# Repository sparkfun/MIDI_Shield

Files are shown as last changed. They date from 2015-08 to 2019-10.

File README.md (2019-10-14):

SparkFun MIDI Shield
====================

SparkFun MIDI Shield (https://www.sparkfun.com/products/12898)

[*SparkFun MIDI Shield (DEV-12898)*](https://www.sparkfun.com/products/12898)

The MIDI Shield gives your Arduino access to the MIDI communication protocol, so you can control synthesizers, sequencers, and other musical devices.

Repository Contents
-------------------

* **/Firmware** - Example Arduino .ino sketch
* **/Hardware** - All Eagle design files (.brd, .sch)
* **/Production** - Production panel files (.brd)

Documentation
--------------
* **[Hookup Guide](https://learn.sparkfun.com/tutorials/midi-shield-hookup-guide?_ga=1.24780723.863167751.1453149924)** - Basic hookup guide for the MIDI Shield.
* **[SparkFun Fritzing repo](https://github.com/sparkfun/Fritzing_Parts)** - Fritzing diagrams for SparkFun products.
* **[SparkFun 3D Model repo](https://github.com/sparkfun/3D_Models)** - 3D models of SparkFun products. 
* **[SparkFun Graphical Datasheets](https://github.com/sparkfun/Graphical_Datasheets)** -Graphical Datasheets for various SparkFun products.

Product Versions
----------------
* [DEV-12898](https://www.sparkfun.com/products/12898)- Version 1.5. R3 compatible. Currently live. 
* [DEV-09595](https://www.sparkfun.com/products/retired/9595)- Version 1.3. Retired. 

Version History
---------------
* [V_1.5](https://github.com/sparkfun/MIDI_Shield/tree/V_1.5) - GitHub snapshot at V_1.5. 
* [V_1.3](https://github.com/sparkfun/MIDI_Shield/tree/v1.3) - GitHub snapshot at V_1.3

License Information
-------------------

This product is _**open source**_! 

Please review the LICENSE.md file for license information. 

If you have any questions or concerns on licensing, please contact techsupport@sparkfun.com.

Distributed as-is; no warranty is given.

\- Your friends at SparkFun.

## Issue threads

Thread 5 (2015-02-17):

90 degree trace under opto IC needs to be fixed

SFE-KADE, 2015-02-17:

Jacquot-SFE, 2015-02-17:
Can you give me an x,y coordinate?  I'm not seeing a right angle under the IC.

SFE-KADE, 2015-02-17:
Sorry, I meant "off of IC" not under. It's under the prog silk just north of the IC.

Jacquot-SFE, 2015-02-17:
Got it!

Closed 2015-02-17.

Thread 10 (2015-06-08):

brd needs measurements on measures layer

SFE-KADE, 2015-06-08:
Since there are connectors on this that can be flush mounted with a custom enclosure we should include measurements.

Jacquot-SFE, 2015-06-08:
Got 'em.

Closed 2015-06-08.

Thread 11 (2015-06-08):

Standoff holes in brd?

SFE-KADE, 2015-06-08:
Should we include them for use in an enclosure?

SFE-KADE, 2015-06-08:
I use the terms "standoff" and "mounting" here interchangeably.

Jacquot-SFE, 2015-06-08:
I skipped them on purpose.

Mechanically, this thing doesn't really provide for easy mounting in an
enclosure.  The connectors are tall, much taller than the adjacent
pushbuttons.  If it's mounted on a Uno or Redboard, the shield is
considerably shorter than the host board - the USB connector sticks out
about 3/4" past the MIDI plugs.

I suppose we could include the one hole near the SCL pin, but it's mostly
useless because it's too close to the header.

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

SFE-KADE, 2015-06-08:
Your call.

Closed 2015-06-08.

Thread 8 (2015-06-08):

version number correct?

SFE-KADE, 2015-06-08:
I think standard protocol dictates that the version number should still be v15 even though we proto'd a v15 already, only because the live version of the product is v14. The version increment should stay v15 through however many rounds of proto we do in this case. Toni, can you confirm?

Jacquot-SFE, 2015-06-08:
You're right.

(As Per an old discussion with Abe) They never made it to production, so it won't introduce inventory problems if the number doesn't roll.

Back to 1.5.

Closed 2015-06-08.

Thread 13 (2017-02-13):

using soft serial on pins 8 and 9

1mpar, 2017-02-13:
hi, I'm using this code - https://github.com/sparkfun/MIDI_Shield/blob/master/Firmware/MIDI-sniffer/MIDI-sniffer.ino
but I get no messages on the serial monitor. I think this code is for the new version of the shield, but is there a way to use soft serial on pins 8 and 9 on this version (sparkfun DEV 09595)?

Jacquot-SFE, 2017-02-17:
If you're comfortable reworking the board a little bit, this is doable.

You can cut the TX and RX lines, and add jumpers to run them to pins 8 and 9.  I'd cut the RX line near the "G" in PROG, so the 220-Ohm resistor is still tied to the optocoupler, before it reaches the RUN/PROG switch.  You can cut the TX line anywhere between the shield pin and the 220-Ohm resistor, since there's no interceding circuitry.

bboyho, 2019-02-11:
Hi,

It looks like Byron answered your question. The code is written for the latest MIDI Shield. However, as Byron stated above, you can reroute the pins on an ATmega328P-based Arduino to software serial and view the data on an Arduino Serial Monitor. Just make sure to select the correct baud rate since the output is 19200 baud.

Closed 2019-02-11.

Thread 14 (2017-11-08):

Question: how to make an arpeggio?

billyjoker, 2017-11-08:
Hi, i have this shield and i would like to write some arpeggios, but i do not know how to handle it. Thanks!!

Jacquot-SFE, 2017-11-14:
Howdy Billy,

I assume you want to build something like an arpeggiator on a keyboard, where you hold some notes, and the device will cycle through them?  If not, please add some detail about what you're trying to achieve.

I notice you found wbajzek's arpeggiator.

There's also the Mutable Instrument's [MIDIPal](https://github.com/pichenettes/midipal), which is a MIDI toolkit that includes an arpeggiator.

Finally, I put an arpeggiator in my [Werkstatt CV converter](https://learn.sparkfun.com/tutorials/midi-shield-hookup-guide/example-2-midi-to-control-voltage) project, but it outputs control voltage, not MIDI messages.  You could probably amend it to send MIDI instead.

-BGJ

billyjoker, 2017-11-15:
Hi @Jacquot-SFE !!

Yes, i'd like to trigger some arpeggiated notes when i hold on a note in my midi keyboard. You are right, i've tried the  wbajzek's arpeggiator, but the performance is not very well...

My goal is to have stored a kit of arpeggios, select one of them, and trigger it with my midi keyboard.

I've just take a look at the Mutable Instrument's MIDIPal, can i load it to my Arduino? As i saw, it is written with Python....

I'm taking a look also to your Werkstatt CV converter, is this the [code](https://github.com/sparkfun/MIDI_Shield/blob/V_1.5/Firmware/MIDI-CV/MIDI-CV.ino) ?

Thanks again!!!

Jacquot-SFE, 2017-11-16:
A couple of thoughts on this.

First, I'm not sure you're describing that a traditional arpeggiator does.  An old-school arpeggiator takes a handful of held keys, and hops between them based on some rule (up, down, up&down, random, etc).  You might check for videos of the old Roland SH101 arpeggiator in action.  It's got a pretty good one.

I take it you're looking for something that will start playing a predefined group of notes based on a single key press?  I'm not sure what it would be called, maybe an interactive phrase sequencer?

Either way, you should be able to make one using an Arduino + MIDI  shield...you just might not find one already written.

I haven't tried either wbajzek's or the MIDI pal, I just found them googling.  The MIDIPal was mentioned by a friend recently - it's based on an ATMEGA328P and standard MIDI hardware...which looks like a subset of an Uno & MIDI Shield.  The firmware is in [this subtree](https://github.com/pichenettes/midipal/tree/master/midipal), and the Python piece looks like a configuration app that runs alongside, since the MIDIpal itself only has a knob and small LCD.

Finally, that is my CV converter.  You'll also need the `notemap` files from that directory, and the fortyseven effects [MIDI library](http://github.com/FortySevenEffects/arduino_midi_library/).

bboyho, 2019-02-11:
Hi,

It looks like Byron might have answered your questions. I'll be be closing this issue. If you have not already, it might be good to check out the SparkFun or Arduino.cc Forums to see if you can get some additional insight from others in the community on arpeggios. =) :

* [Arduino.cc Forums](https://forum.arduino.cc/)
* [SparkFun Forums](https://forum.sparkfun.com/)

Closed 2019-02-11.

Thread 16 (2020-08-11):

Is this sketch only compatible with the SparkFun MIDI-shield?

m-r-m-s, 2020-08-11:
I am _not_ using the sparkfun MIDI shield but I have built a MIDI I/O circuit according to MIDI specs.

The MIDI I/O circuit works with no issues when receiving input from a sequencer and the output goes to a software synthesizer sound source. Here is a [link](https://forum.arduino.cc/index.php?topic=699623.msg4702301#msg4702301) to the I/O circuit I have built.

I have tested this circuit using the Arduino MIDI library (fortyseven effects) basic I/O and callback examples. No issues whatsoever.

The issue I am having with the MIDI-sniffer.ino sketch is that while the serial monitor seems to be reading all the MIDI data, the output seems to be getting "stuck". Notes sent from the sequencer will get stuck "on", and after I stop the sequencer, I hear a distinct echo/ feedback noise coming from the receiving sound source.

As a result, I have to reset the MIDI output (send note off / panic message) in my DAW to stop the noise from continuing and "unstick" things. Is this some kind of loopback?

Why do the basic I/O and callback examples provided in the Arduino MIDI library work but this sketch has issues? How can I work to resolve this issue? Any guidance or pointers is greatly appreciated.

Jacquot-SFE, 2020-08-14:
So the dirty little secret of NewSoftSerial - it's half-duplex.  Sending and receiving at the same time can interfere with one another.  It'll get worse as the port utilization rises - tapping one key on a MIDI controller might be OK, while heavy multi-channel sequencer (with clocks, controllers, etc) data might not.

There are a couple things to try.

To have a reliable MIDI-thru for the sniffer, you could feed the TTL signal recovered from the input straight to the output driver - that would be akin to the out/thru solder jumper (SJ3) on the shield.

Alternatively, use a chip with multiple hardware UARTs, like an Arduino Mega or Teensy.

m-r-m-s, 2020-08-14:
@Jacquot-SFE  Thank you! I figured it was something related to the sequencer's heavier input and you have certainly confirmed it. I am currently working with an UNO but will consider the Mega or Teensy for the future.

In the meantime, can you say more about "feeding the TTL signal recovered from the input straight to the output driver"?

Currently, I have a sequencer connected to my MIDI IN circuit which is connected to pin 8 (Rx) on the UNO and the MIDI OUT circuit is connected at pin 9 (Tx). Apologies in advance for the lack of knowledge, but how would I achieve what you suggested in this in the circuit?

For reference, these are the schematics of my [input](https://www.limulo.net/website/assets/images/midi-interface/MIDI_IN_bb_new.png) and [output](https://www.limulo.net/website/assets/images/midi-interface/MIDI_OUT_bb_new.png) circuit. Thank you for all the assistance so far.

Jacquot-SFE, 2020-08-17:
To make the out into a thru, unplug the purple with from Arduino pin 10.  Plug it into pin 6 of the optocoupler, where the green wire to Ard 11 is.

It's probably not the most robust solution - a typical MIDI thru uses a logic gate of some sort to buffer & drive the thru.  The shield uses a 74ahc1g125, the old MMA circuit uses series pairs of inverters (invert, then invert again).

m-r-m-s, 2020-08-17:
@Jacquot-SFE thank you so so much. Just gave the thru circuit a try and it worked great! I really appreciate your guidance here. I will look into building a more robust MIDI thru circuit with the buffer you referenced.

Closed 2020-08-20.

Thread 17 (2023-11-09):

Verify/compile of MIDI-sniffer fails

kciszewski, 2023-11-09:
When compiling on Aurdiuno IDE the error message "MIDI-sniffer:41:10: fatal error: MsTimer2.h: No such file or directory
 #include <MsTimer2.h>"

I'm using Arduino 1.8.19

Where do I find MsTimer2.h?

kciszewski, 2023-11-09:
I found it thanks!  I'm somewhat new to Arduino

edspark, 2023-11-09:
MsTImer2 is an [Arduino Library](https://www.arduino.cc/reference/en/libraries/mstimer2/) that you can find using the Library Manger. I don't have 1.8 on my computer but it's an old library that still exists even in Arduino 2.2.

edspark, 2023-11-09:
Ah you beat me to it, cheers!

Closed 2023-11-09.

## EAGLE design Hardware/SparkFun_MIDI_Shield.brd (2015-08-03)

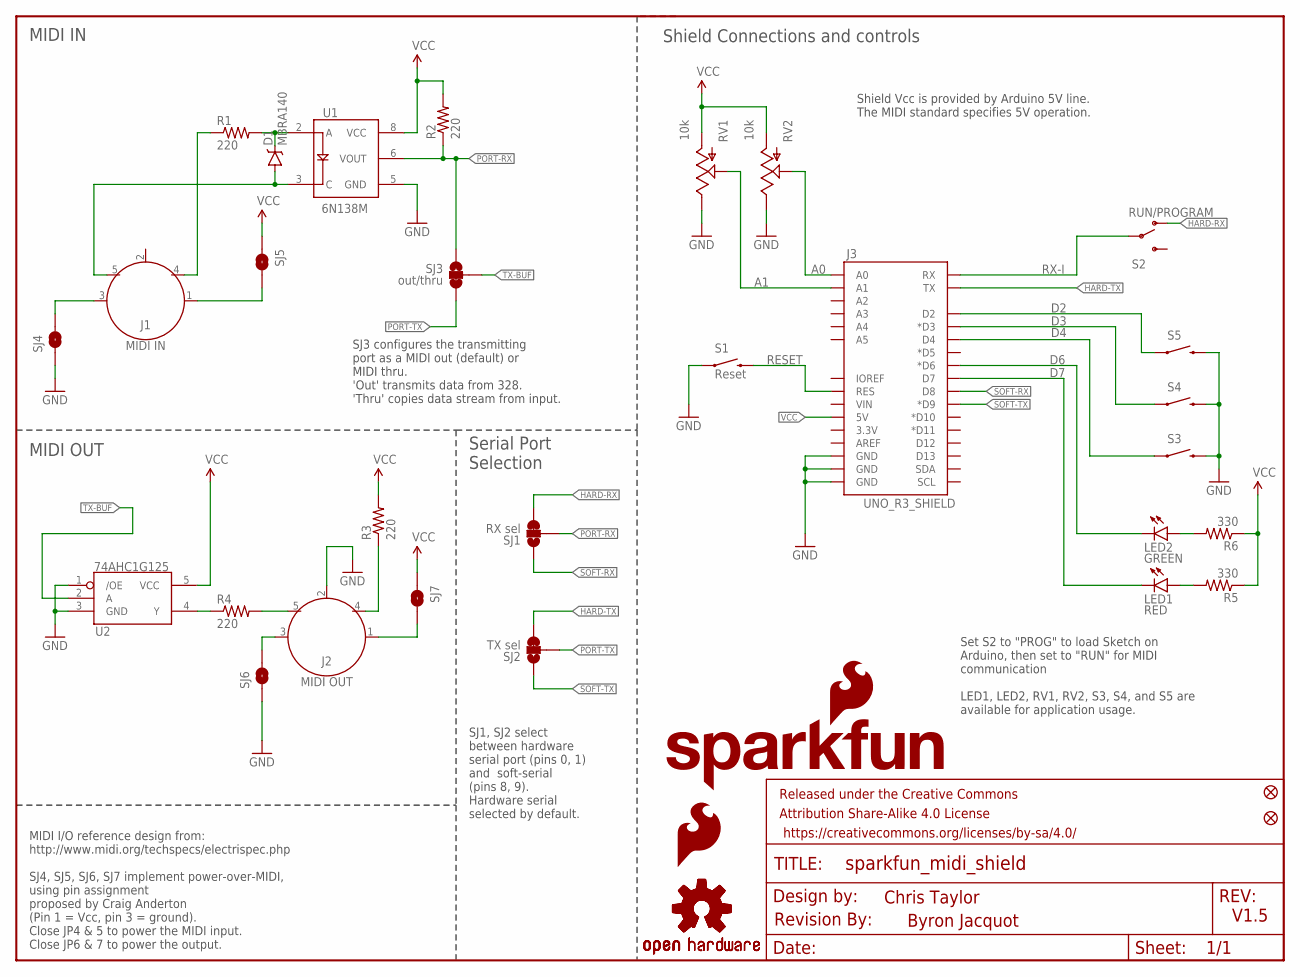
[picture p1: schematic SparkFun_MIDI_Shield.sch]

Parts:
D1: MBRA140; SMA-DIODE
FID1, FID2: FIDUCIALUFIDUCIAL; MICRO-FIDUCIAL
FRAME1: Frame; CREATIVE_COMMONS
J1: MIDI IN; 5-PIN-DIN-RA-PCB-NEW
J2: MIDI OUT; 5-PIN-DIN-RA-PCB-NEW
J3: UNO_R3_SHIELD
LED1: RED; LED-0603
LED2: GREEN; LED-0603
LOGO1: SFE_LOGO_NAME_FLAME.2_INCH; SFE_LOGO_NAME_FLAME_.2
LOGO2: OSHW-LOGOS; OSHW-LOGO-S
LOGO3: OSHW-LOGOM; OSHW-LOGO-M
LOGO5: SFE_LOGO_FLAME.1_INCH; SFE_LOGO_FLAME_.1
R1, R2, R3, R4: 220; 0603-RES
R5, R6: 330; 0603-RES
RV1, RV2: 10k; ALPS_POT
S1: Reset; TACTILE-SWITCH-SMD
S2: RUN/PROGRAM; AYZ0202
S3, S4, S5: SWITCH-MOMENTARY-212MM; TACTILE-PTH-12MM
SJ1: RX sel; PAD-JUMPER-3-2OF3_NC_BY_TRACE_YES_SILK_FULL_BOX
SJ2: TX sel; PAD-JUMPER-3-2OF3_NC_BY_TRACE_YES_SILK_FULL_BOX
SJ3: out/thru; PAD-JUMPER-3-2OF3_NC_BY_TRACE_YES_SILK_FULL_BOX
SJ4, SJ5, SJ6, SJ7: JUMPER-PAD-2-NOYES_SILK; PAD-JUMPER-2-NO_YES_SILK
U1: 6N138M; 8-SMD
U2: 74AHC1G125; SOT23-5
U$1: REVISION

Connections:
56: D1.C, R1.2, U1.2 (A)
1235: J2.4, R3.1
A0: J3.A0, RV2.P$2 (S)
A1: J3.A1, RV1.P$2 (S)
D2: J3.D2, S5.1
D3: J3.D3 (*D3), S4.1
D4: J3.D4, S3.1
D6: J3.D6 (*D6), LED2.C
D7: J3.D7, LED1.C
GND: J2.2, J3.GND@0 (GND), J3.GND@1 (GND), J3.GND@2 (GND), RV1.P$1 (E), RV2.P$1 (E), S1.1, S3.3 (2), S4.3 (2), S5.3 (2), SJ4.1, SJ6.1, U1.5 (GND), U2.1 (/OE), U2.3 (GND)
HARD-RX: S2.1 (O), SJ1.3
HARD-TX: J3.TX, SJ2.3
unnamed: J2.5, R4.2
unnamed: J1.4, R1.1
unnamed: R4.1, U2.4 (Y)
unnamed: J2.3, SJ6.2
unnamed: J2.1, SJ7.2
unnamed: J1.3, SJ4.2
unnamed: J1.1, SJ5.2
unnamed: LED1.A, R5.2
unnamed: LED2.A, R6.2
PIN5: D1.A, J1.5, U1.3 (C)
PORT-RX: R2.1, SJ1.2, SJ3.1, U1.6 (VOUT)
PORT-TX: SJ2.2, SJ3.3
RESET: J3.RES, S1.3 (2)
RX-I: J3.RX, S2.2
SOFT-RX: J3.D8, SJ1.1
SOFT-TX: J3.D9 (*D9), SJ2.1
TX-BUF: SJ3.2, U2.2 (A)
VCC: J3.5V, R2.2, R3.2, R5.1, R6.1, RV1.P$3 (A), RV2.P$3 (A), SJ5.1, SJ7.1, U1.8 (VCC), U2.5 (VCC)

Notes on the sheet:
MIDI IN
MIDI OUT
Byron Jacquot
V1.5
Shield Connections and controls
MIDI I/O reference design from: http://www.midi.org/techspecs/electrispec.php SJ4, SJ5, SJ6, SJ7 implement power-over-MIDI, using pin assignment proposed by Craig Anderton (Pin 1 = Vcc, pin 3 = ground). Close JP4 & 5 to power the MIDI input. Close JP6 & 7 to power the output.
Set S2 to "PROG" to load Sketch on Arduino, then set to "RUN" for MIDI communication LED1, LED2, RV1, RV2, S3, S4, and S5 are available for application usage.
Serial Port Selection
SJ1, SJ2 select between hardware serial port (pins 0, 1) and soft-serial (pins 8, 9). Hardware serial selected by default.
Shield Vcc is provided by Arduino 5V line. The MIDI standard specifies 5V operation.
SJ3 configures the transmitting port as a MIDI out (default) or MIDI thru. 'Out' transmits data from 328. 'Thru' copies data stream from input.
Chris Taylor

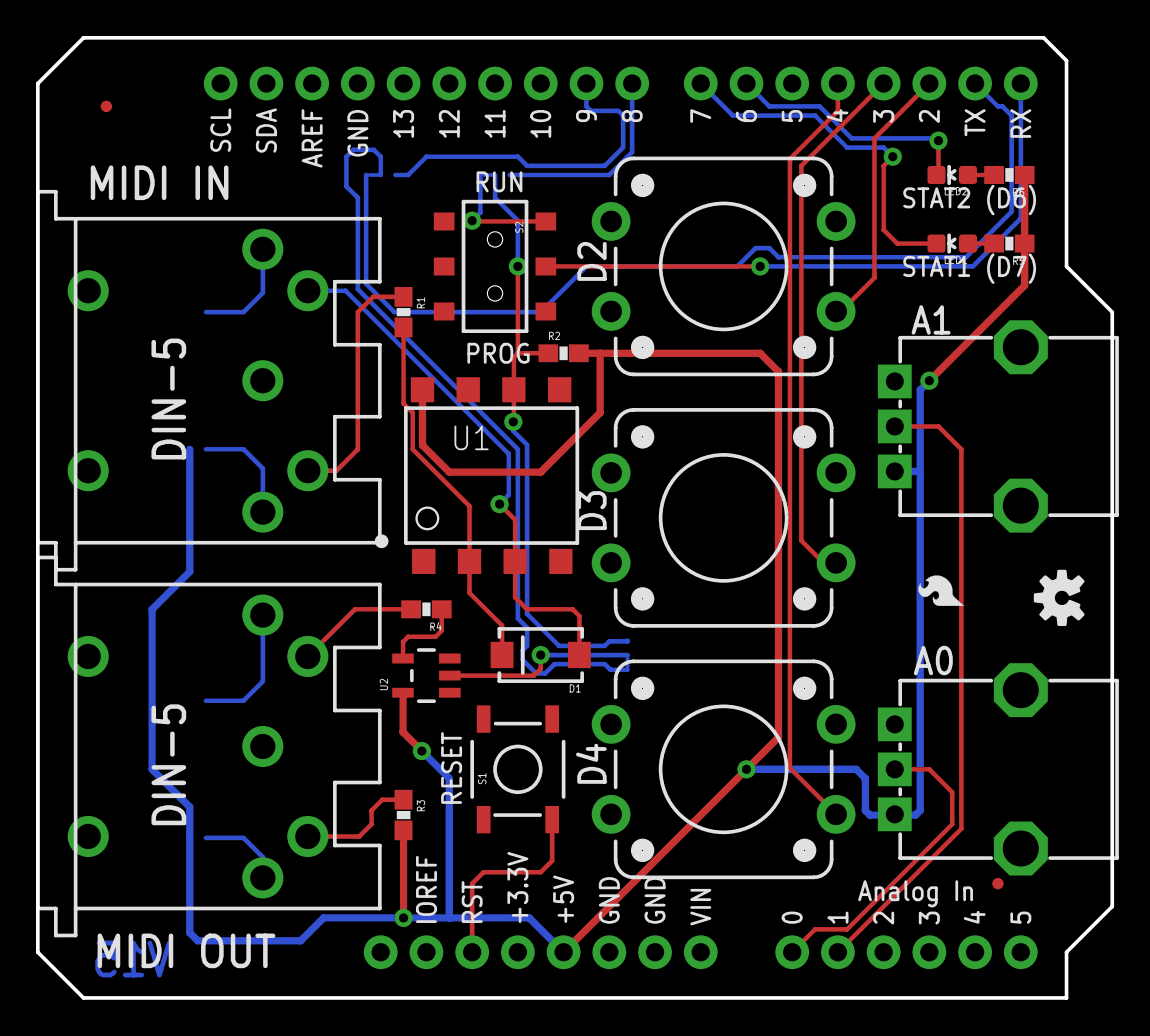
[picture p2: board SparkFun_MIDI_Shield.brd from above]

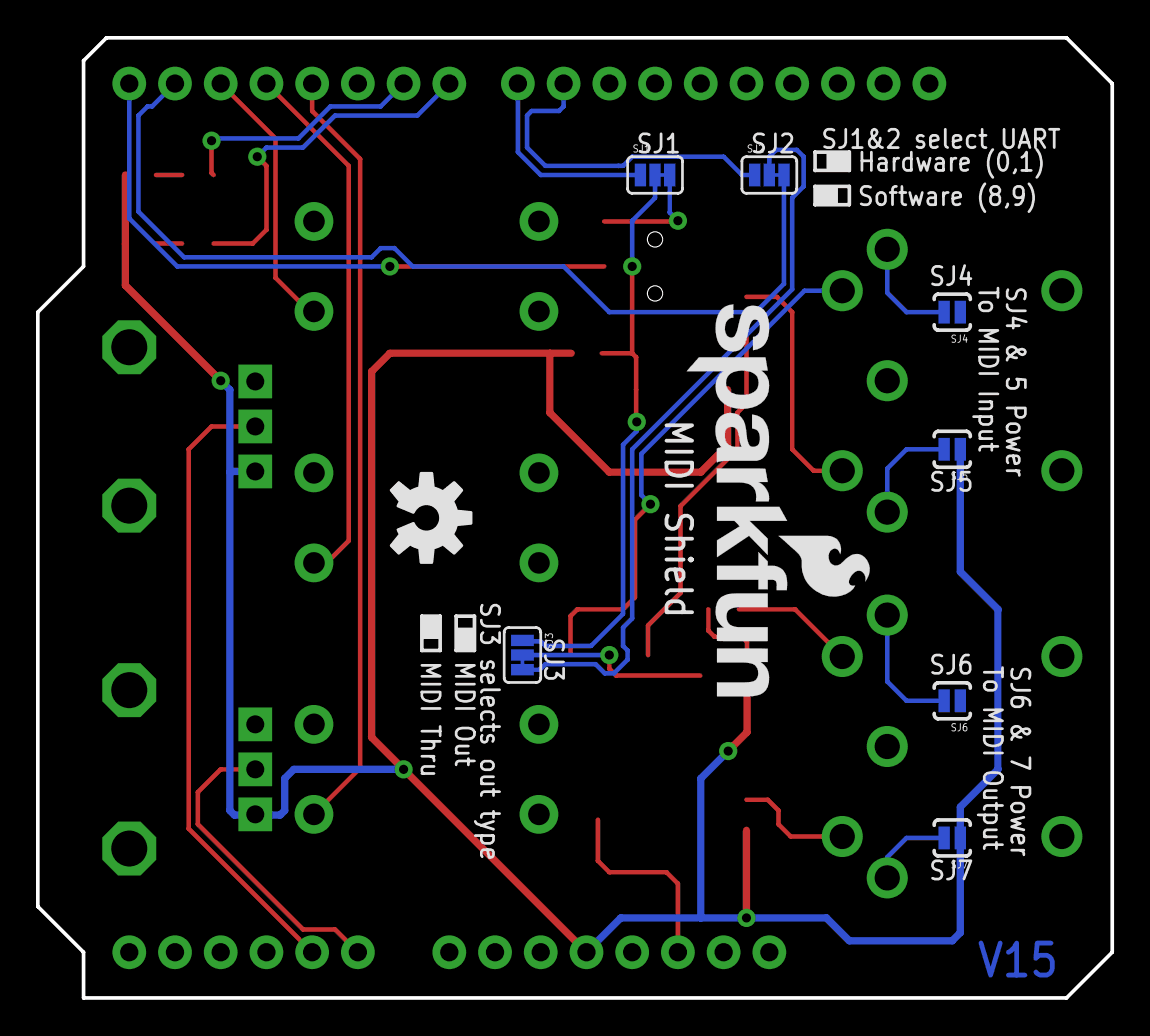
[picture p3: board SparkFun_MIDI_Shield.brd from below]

Board: 3 copper layers, 59.7 x 53.3 mm, 36 parts (9 on the bottom side), 30 nets.

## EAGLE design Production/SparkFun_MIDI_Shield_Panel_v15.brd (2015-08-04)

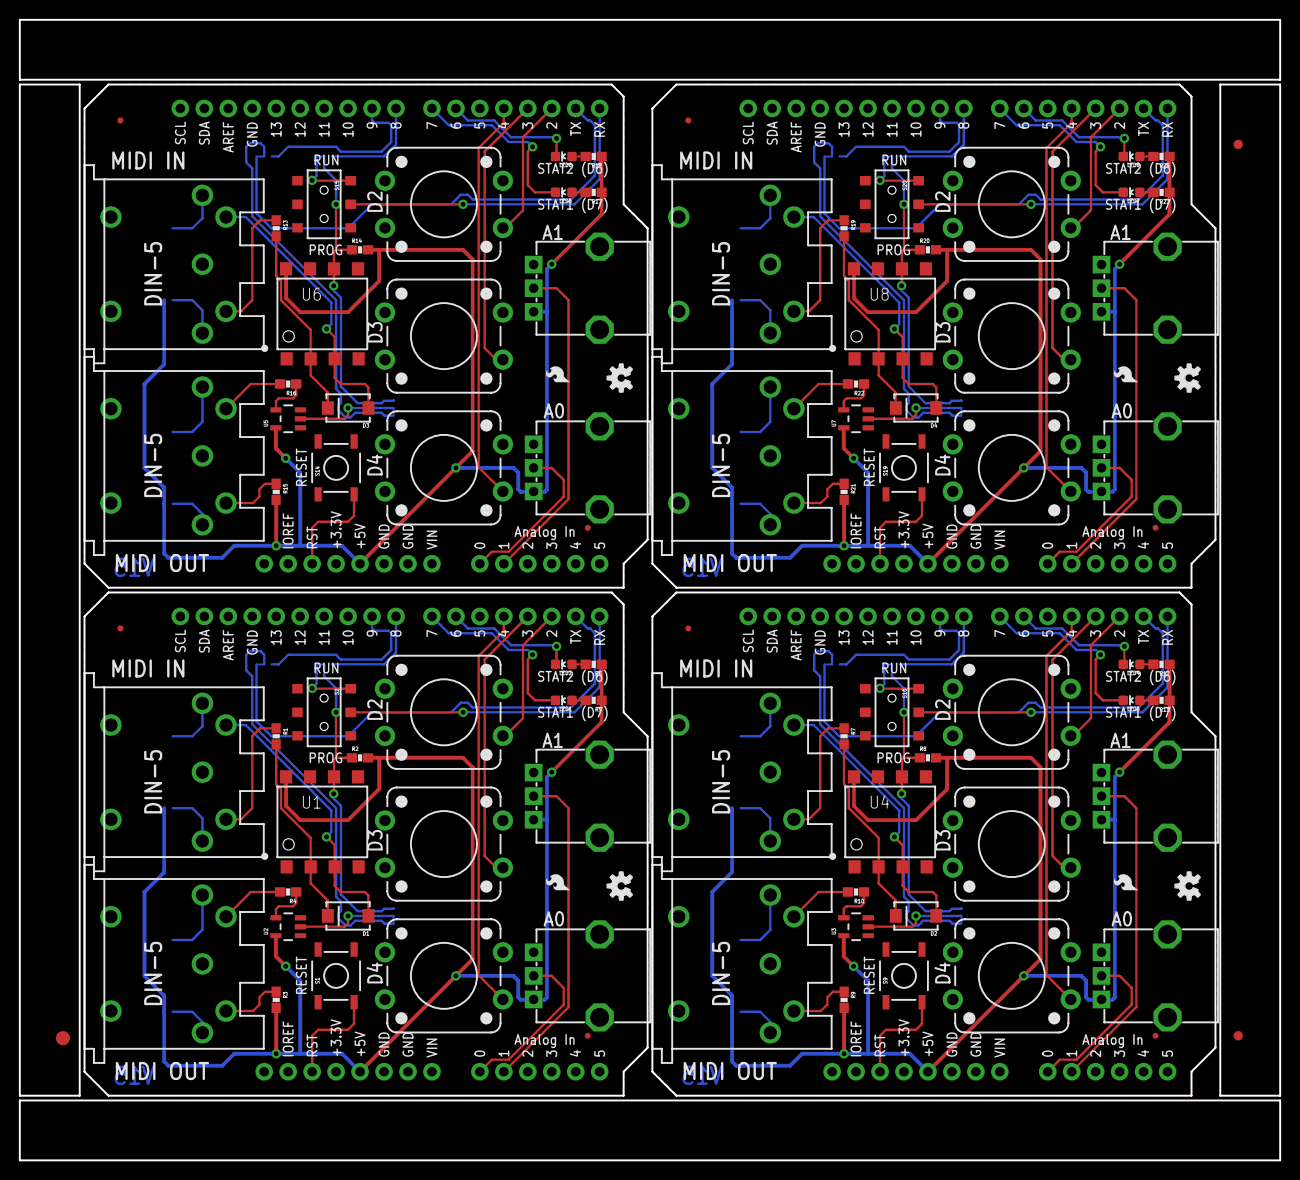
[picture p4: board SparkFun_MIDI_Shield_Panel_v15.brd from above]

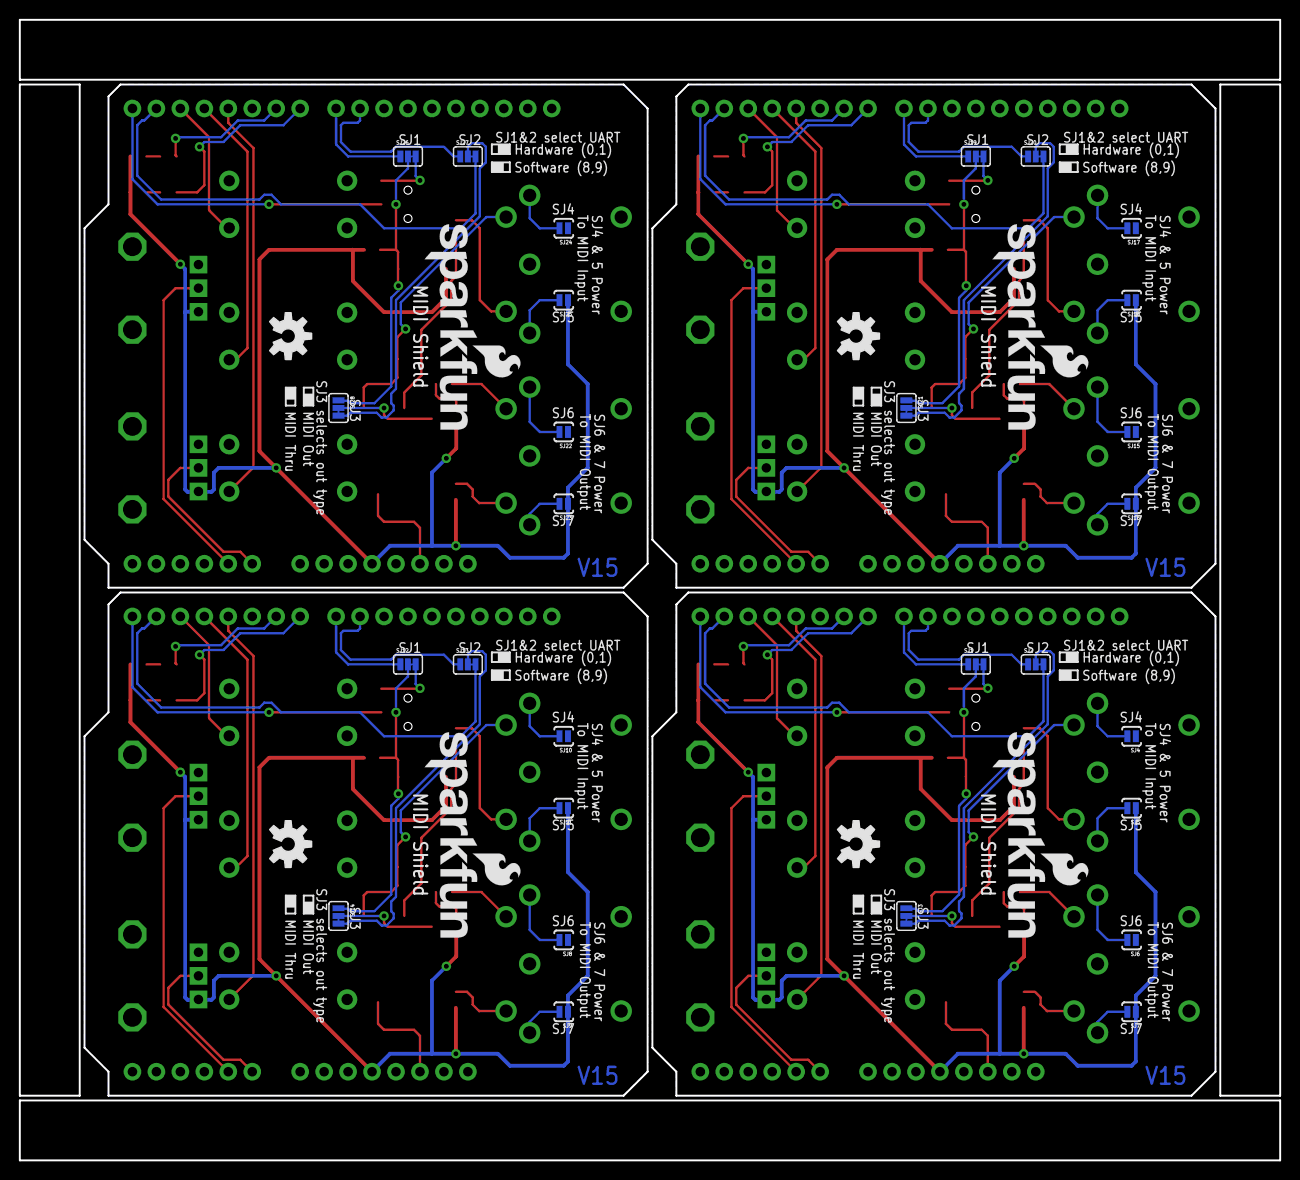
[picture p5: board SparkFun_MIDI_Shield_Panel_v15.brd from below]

Board: 3 copper layers, 133.6 x 120.9 mm, 139 parts (36 on the bottom side), 120 nets.

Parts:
D1, D2, D3, D4: MBRA140; SMA-DIODE
E$1: FIDUCIAL-1.5X3
E$4, E$5: FIDUCIAL-1X2
FID1, FID2, FID3, FID4, FID5, FID6, FID7, FID8: FIDUCIALUFIDUCIAL; MICRO-FIDUCIAL
J1, J4, J7, J10: MIDI IN; 5-PIN-DIN-RA-PCB-NEW
J2, J5, J8, J11: MIDI OUT; 5-PIN-DIN-RA-PCB-NEW
J3, J6, J9, J12: UNO_R3_SHIELD
LED1, LED3, LED5, LED7: RED; LED-0603
LED2, LED4, LED6, LED8: GREEN; LED-0603
LOGO1, LOGO4, LOGO9, LOGO13: SFE_LOGO_NAME_FLAME.2_INCH; SFE_LOGO_NAME_FLAME_.2
LOGO2, LOGO6, LOGO10, LOGO14: OSHW-LOGOS; OSHW-LOGO-S
LOGO3, LOGO7, LOGO11, LOGO15: OSHW-LOGOM; OSHW-LOGO-M
LOGO5, LOGO8, LOGO12, LOGO16: SFE_LOGO_FLAME.1_INCH; SFE_LOGO_FLAME_.1
R1, R2, R3, R4, R7, R8, R9, R10, R13, R14, R15, R16, R19, R20, R21, R22: 220; 0603-RES
R5, R6, R11, R12, R17, R18, R23, R24: 330; 0603-RES
RV1, RV2, RV3, RV4, RV5, RV6, RV7, RV8: 10k; ALPS_POT
S1, S9, S14, S19: Reset; TACTILE-SWITCH-SMD
S2, S10, S15, S20: RUN/PROGRAM; AYZ0202
S3, S4, S5, S6, S7, S8, S11, S12, S13, S16, S17, S18: SWITCH-MOMENTARY-212MM; TACTILE-PTH-12MM
SJ1, SJ12, SJ19, SJ26: RX sel; PAD-JUMPER-3-2OF3_NC_BY_TRACE_YES_SILK_FULL_BOX
SJ2, SJ13, SJ20, SJ27: TX sel; PAD-JUMPER-3-2OF3_NC_BY_TRACE_YES_SILK_FULL_BOX
SJ3, SJ14, SJ21, SJ28: out/thru; PAD-JUMPER-3-2OF3_NC_BY_TRACE_YES_SILK_FULL_BOX
SJ4, SJ5, SJ6, SJ7, SJ8, SJ9, SJ10, SJ11, SJ15, SJ16, SJ17, SJ18, SJ22, SJ23, SJ24, SJ25: JUMPER-PAD-2-NOYES_SILK; PAD-JUMPER-2-NO_YES_SILK
U1, U4, U6, U8: 6N138M; 8-SMD
U2, U3, U5, U7: 74AHC1G125; SOT23-5

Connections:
1: D2.C, R7.2, U4.2
2: J5.4, R9.1
3: D3.C, R13.2, U6.2
4: J8.4, R15.1
5: D4.C, R19.2, U8.2
6: J11.4, R21.1
56: D1.C, R1.2, U1.2
1235: J2.4, R3.1
A0: J3.A0, RV2.P$2
A1: J3.A1, RV1.P$2
A2: J6.A1, RV3.P$2
A3: J6.A0, RV4.P$2
A4: J9.A1, RV5.P$2
A5: J9.A0, RV6.P$2
A6: J12.A1, RV7.P$2
A7: J12.A0, RV8.P$2
D1: J6.D2, S8.1
D2: J3.D2, S5.1
D3: J3.D3, S4.1
D4: J3.D4, S3.1
D5: J6.D3, S7.1
D6: J3.D6, LED2.C
D7: J3.D7, LED1.C
D8: J6.D4, S6.1
D9: J6.D7, LED3.C
D10: J6.D6, LED4.C
D11: J9.D2, S13.1
D12: J9.D3, S12.1
D13: J9.D4, S11.1
D14: J9.D7, LED5.C
D15: J9.D6, LED6.C
D16: J12.D2, S18.1
D17: J12.D3, S17.1
D18: J12.D4, S16.1
D19: J12.D7, LED7.C
D20: J12.D6, LED8.C
GND: J2.2, J3.GND@0, J3.GND@1, J3.GND@2, RV1.P$1, RV2.P$1, S1.1, S3.3, S4.3, S5.3, SJ4.1, SJ6.1, U1.5, U2.1, U2.3
GND1: J5.2, J6.GND@0, J6.GND@1, J6.GND@2, RV3.P$1, RV4.P$1, S6.3, S7.3, S8.3, S9.1, SJ8.1, SJ10.1, U3.1, U3.3, U4.5
GND2: J8.2, J9.GND@0, J9.GND@1, J9.GND@2, RV5.P$1, RV6.P$1, S11.3, S12.3, S13.3, S14.1, SJ15.1, SJ17.1, U5.1, U5.3, U6.5
GND3: J11.2, J12.GND@0, J12.GND@1, J12.GND@2, RV7.P$1, RV8.P$1, S16.3, S17.3, S18.3, S19.1, SJ22.1, SJ24.1, U7.1, U7.3, U8.5
HARD-RX: S2.1, SJ1.3
HARD-RX1: S10.1, SJ12.3
HARD-RX2: S15.1, SJ19.3
HARD-RX3: S20.1, SJ26.3
HARD-TX: J3.TX, SJ2.3
HARD-TX1: J6.TX, SJ13.3
HARD-TX2: J9.TX, SJ20.3
HARD-TX3: J12.TX, SJ27.3
unnamed: J2.5, R4.2
unnamed: J1.4, R1.1
unnamed: R4.1, U2.4
unnamed: J2.3, SJ6.2
unnamed: J2.1, SJ7.2
unnamed: J1.3, SJ4.2
unnamed: J1.1, SJ5.2
unnamed: LED3.A, R11.2
unnamed: LED1.A, R5.2
unnamed: LED2.A, R6.2
unnamed: LED4.A, R12.2
unnamed: J4.4, R7.1
unnamed: J5.5, R10.2
unnamed: R10.1, U3.4
unnamed: J5.3, SJ8.2
unnamed: J5.1, SJ9.2
unnamed: J4.3, SJ10.2
unnamed: J4.1, SJ11.2
unnamed: LED5.A, R17.2
unnamed: LED6.A, R18.2
unnamed: J7.4, R13.1
unnamed: J8.5, R16.2
unnamed: R16.1, U5.4
unnamed: J8.3, SJ15.2
unnamed: J8.1, SJ16.2
unnamed: J7.3, SJ17.2
unnamed: J7.1, SJ18.2
unnamed: LED7.A, R23.2
unnamed: LED8.A, R24.2
unnamed: J10.4, R19.1
unnamed: J11.5, R22.2
unnamed: R22.1, U7.4
unnamed: J11.3, SJ22.2
unnamed: J11.1, SJ23.2
unnamed: J10.3, SJ24.2
unnamed: J10.1, SJ25.2
PIN1: D2.A, J4.5, U4.3
PIN2: D3.A, J7.5, U6.3
PIN3: D4.A, J10.5, U8.3
PIN5: D1.A, J1.5, U1.3
PORT-RX: R2.1, SJ1.2, SJ3.1, U1.6
PORT-RX1: R8.1, SJ12.2, SJ14.1, U4.6
PORT-RX2: R14.1, SJ19.2, SJ21.1, U6.6
PORT-RX3: R20.1, SJ26.2, SJ28.1, U8.6
PORT-TX: SJ2.2, SJ3.3
PORT-TX1: SJ13.2, SJ14.3
PORT-TX2: SJ20.2, SJ21.3
PORT-TX3: SJ27.2, SJ28.3
RESET: J3.RES, S1.3
RESET1: J6.RES, S9.3
RESET2: J9.RES, S14.3
RESET3: J12.RES, S19.3
RX-I: J3.RX, S2.2
RX-I1: J6.RX, S10.2
RX-I2: J9.RX, S15.2
RX-I3: J12.RX, S20.2
SOFT-RX: J3.D8, SJ1.1
SOFT-RX1: J6.D8, SJ12.1
SOFT-RX2: J9.D8, SJ19.1
SOFT-RX3: J12.D8, SJ26.1
SOFT-TX: J3.D9, SJ2.1
SOFT-TX1: J6.D9, SJ13.1
SOFT-TX2: J9.D9, SJ20.1
SOFT-TX3: J12.D9, SJ27.1
TX-BUF: SJ3.2, U2.2
TX-BUF1: SJ14.2, U3.2
TX-BUF2: SJ21.2, U5.2
TX-BUF3: SJ28.2, U7.2
VCC: J3.5V, R2.2, R3.2, R5.1, R6.1, RV1.P$3, RV2.P$3, SJ5.1, SJ7.1, U1.8, U2.5
VCC1: J6.5V, R8.2, R9.2, R11.1, R12.1, RV3.P$3, RV4.P$3, SJ9.1, SJ11.1, U3.5, U4.8
VCC2: J9.5V, R14.2, R15.2, R17.1, R18.1, RV5.P$3, RV6.P$3, SJ16.1, SJ18.1, U5.5, U6.8
VCC3: J12.5V, R20.2, R21.2, R23.1, R24.1, RV7.P$3, RV8.P$3, SJ23.1, SJ25.1, U7.5, U8.8

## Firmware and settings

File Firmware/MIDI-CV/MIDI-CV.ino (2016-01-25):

/******************************************************************************
MIDI-CV.ino
MIDI to Control Voltage converter for synthesizers.
Byron Jacquot, SparkFun Electronics
October 2, 2015
https://github.com/sparkfun/MIDI_Shield/tree/V_1.5/Firmware/MIDI-CV

This functions as a MIDI-to-control voltage interface for analog synthesizers.
It was developed for the Moog Werkstatt WS-01, but should work with any volt-per-octave
synthesizer.

Resources:
  This code is dependent on the FortySevenEffects MIDI library for Arduino.
  https://github.com/FortySevenEffects/arduino_midi_library
  This was done using version 4.2, hash fb693e724508cb8a473fa0bf1915101134206c34
  This library is now under the MIT license, as well.
  You'll need to install that library into the Arduino IDE before compiling.

  It is also dependent on the notemap class, stored in the same repository (notemap.cpp/h).

Development environment specifics:
  It was developed for the Arduino Uno compatible SparkFun RedBoard, with a  SparkFun
  MIDI Shield and a pair of Microchip MCP4725 DACs to generate the control voltages.
    
  Written, compiled and loaded with Arduino 1.6.5

This code is released under the [MIT License](http://opensource.org/licenses/MIT).

Please review the LICENSE.md file included with this example. If you have any questions 
or concerns with licensing, please contact techsupport@sparkfun.com.

Distributed as-is; no warranty is given.
******************************************************************************/

#include <SoftwareSerial.h>
#include <MsTimer2.h>
#include <MIDI.h>
#include <Wire.h>

#include "notemap.h"

// VERBOSE mode switches MIDI to use soft serial on pins 8 & 9,
// and enables a bunch of debug print messages.
#define VERBOSE 0

// Instantiate the MIDI interface using the macro
// - HardwareSerial is the type of serial port to be used underneath
// the MIDI routines.
// - Serial1 is the name of that portto be used.  On a pro-micro, "Serial"
// is the USB serial port, and "Serial1" is the hardware UART.
// - "MIDI" parameter is the resulting object name.
#if VERBOSE
SoftwareSerial SoftSerial(8, 9);
MIDI_CREATE_INSTANCE(SoftwareSerial, SoftSerial, MIDI);
#else
MIDI_CREATE_INSTANCE(HardwareSerial, Serial, MIDI);
#endif

// Functional assignments to Arduino pin numbers.
// Digital outputs
static const int GATEPIN = 10;
static const int REDLEDPIN = 7;
static const int GREENLEDPIN = 6;

// Analog input
static const int PIN_TEMPO_POT = 1;

// Digital inputs
static const int UPBTNPIN = 2;
static const int DNBTNPIN  = 3;
static const int SHORTBTNPIN= 4;
static const int BTN_DEBOUNCE = 50;

// global variables
//
// notetracker knows which note ons & offs we have seen.
// We refer to it when it's time to generate CV and gate signals,
static notetracker themap;

// Variables for arpeggiator clock.
static uint32_t tempo_delay = 10;
static bool     send_tick = false;

// The last bend records the most recently seen bend message.
// We need to keep track so we can update note CV when we get new notes,
// or new bend messages - we need the other half in order to put them together.
// bend is signed, 14-bit
static int16_t last_bend = 0;

// constants to describe the MIDI input.
// NUM_KEYS is the number of keys we're interpreting
// BASE_KEY is the offset of the lowest key number
static const int8_t NUM_KEYS = 49;
static const int8_t BASE_KEY = 36;

// The tuning constant - representing the DAC conts per semitone
//
// Arrived at using: (((2^<DAC resolution>)/5)/12) * 100
//
// 2^12 = 4096 total DAC counts.
// 4096/5 = 819.2 DAC counts per volt on a 5V supply
// 819.2/12 = dac counts per semitone = 68.26
// times 100 for some extra calculation precision = 6826
static const uint32_t DAC_CAL = 6826;

/* 
 *  void updateCV(uint8_t key)
 *  
 *Converts key number to DAC count value,
 *and sends the value tio the DAC
 */ 
void updateCV(uint8_t key)
{  
#if 0
  Serial.print("KEY: ");
  Serial.print(key);
#endif
  uint32_t val = 400ul + ((key * DAC_CAL)/100ul);

#if 0
  val = last_key * 6826ul;
  Serial.print(" VALa: ");
  Serial.print(val, HEX);
  
  val /= 100;
  Serial.print(" VALb: ");
  Serial.print(val, HEX);

  val += 400 ;
  Serial.print(" VALc: ");
  Serial.print(val, HEX);
#endif
  val += last_bend;

//  Serial.print(" VAL2: ");
//  Serial.println(val, HEX);


  Wire.beginTransmission(0x60);
  Wire.write(byte((val & 0x0f00) >> 8));
  Wire.write(byte(val & 0xff));
  Wire.endTransmission();

}

/*
 * void updateOutputs()
 * 
 *  Update otputs sets the outputs to the current conditions.
 *  Called from note on, note off, arp tick.
 */
void updateOutputs()
{
  uint8_t key;

  key = themap.whichKey();

#if VERBOSE
  Serial.print("key: ");
  Serial.println(key, HEX);
#endif

  // key is in terms of MIDI note number.
  // Constraining the key number to 4 octave range
  // Soc we can do 4 Volts +/- ~0.5V bend range.
  if (key < BASE_KEY)
  {
    key = 0;
  }
  else if ( key > BASE_KEY + NUM_KEYS)
  {
    key = NUM_KEYS;
  }
  else
  {
    key -= BASE_KEY;
  }

  updateCV(key);

  digitalWrite(GATEPIN, themap.getGate());
}

/////////////////////////////////////////////////////////////////////////
// Callbacks for the MIDI parser
/////////////////////////////////////////////////////////////////////////

/* void handleNoteOn(byte channel, byte pitch, byte velocity)
 *  
 *  Called by MIDI parser when note on messages arrive.
 */
void handleNoteOn(byte channel, byte pitch, byte velocity)
{
  // Do whatever you want when a note is pressed.
  // Try to keep your callbacks short (no delays ect)
  // otherwise it would slow down the loop() and have a bad impact
  // on real-time performance.

  Serial.print("on: ");
  Serial.println(pitch , HEX);

  themap.noteOn(pitch);

  updateOutputs();

}

/* void handleNoteOff(byte channel, byte pitch, byte velocity)
 *  
 *  Called by MIDI parser when note off messages arrive.
 */
void handleNoteOff(byte channel, byte pitch, byte velocity)
{
  // Do something when the note is released.
  // Note that NoteOn messages with 0 velocity are interpreted as NoteOffs.
  Serial.print("off: ");
  Serial.println(pitch , HEX);

  themap.noteOff(pitch);

  updateOutputs();
}

/*void handlePitchBend(byte channel, int bend)
 * 
 * Called by parser when bend messages arrive.
 */
void handlePitchBend(byte channel, int bend)
{
#if VERBOSE
  Serial.print("bend: ");
  Serial.println(bend , HEX);
#endif
  // Bend data from the parser is 14 bits, signed, centered
  // on 0.
  // unsigned conversion & dual-7-bit thwacking 
  // already handled by midi parser

  last_bend = bend >> 5;

#if VERBOSE
  Serial.print("newbend: ");
  Serial.println(last_bend, HEX);
#endif

  updateOutputs();
}

/* void handleCC(byte channel, byte number, byte value)
 *  
 *  Called by parser when continuous controller message arrive
 */
void handleCC(byte channel, byte number, byte value)
{
#if VERBOSE
  Serial.print("cc: ");
  Serial.print(number);
  Serial.print(" chan: ");
  Serial.print(channel, HEX);
  Serial.print("val: ");
  Serial.println(value, HEX);
#endif

  switch (number)
  {
    case 1:
    { // Mod wheel

      Wire.beginTransmission(0x61);
      // Turn 7 bits into 12
      Wire.write(byte((value & 0x70) >> 3));
      Wire.write(byte((value & 0x0f) << 4));
      Wire.endTransmission();
    };
    break;
    case 64:
    { // sustain pedal
      themap.setSustain( (value != 0) );            
    }

    // Other CC's would line up here...

    default:
      break;
  }

}

/////////////////////////////////////////////////////////////////////////
// millisecond timer related
//
// See documentation for MStimer2 (http://playground.arduino.cc/Main/MsTimer2).
////////////////////////////////////////////////////////////////////////

void timer_callback()
{
  // Tell the mainline loop that time has elapsed
  send_tick = true;
}

/* void tick_func()
 *  
 * Called by mainline loop when send_tick is true.
 * Keeps track of rising/falling edges, and notifies notetracker
 * of clock status.
 */
void tick_func()
{
  static uint8_t counter = 0;  

  counter++;

  if(counter & 0x01)
  {
    digitalWrite(REDLEDPIN, HIGH);

    themap.tickArp(false);
    updateOutputs();
  }
  else
  {
    digitalWrite(REDLEDPIN, LOW);

    themap.tickArp(true);
    updateOutputs();
  }
}

/////////////////////////////////////////////////////////////////////////
// Panel interface control routines
/////////////////////////////////////////////////////////////////////////

/*void check_pots()
 * 
 * Read the analog input (tempo control)
 */
void check_pots()
{
  uint32_t pot_val;
  uint32_t calc;
  
  pot_val = analogRead(PIN_TEMPO_POT);
  
  // Result is 10 bits
  //calc = (((0x3ff - pot_val) * 75)/1023) + 8;
  calc = (((0x3ff - pot_val) * 1800)/1023) + 25;
  
  tempo_delay = calc  ;

}

/* void up_btn_func()
 *  
 *  Called when button reader detects arpeggio up button has been pressed.
 *  
 *  If not in up mode, turn on up mode.
 *  If in up mode, stops arpeggiator.
 */
void up_btn_func()
{
#if VERBOSE  
  Serial.println("Up!");
#endif

  if(themap.getMode() == notetracker::ARP_UP)
  {
    digitalWrite(GREENLEDPIN, HIGH);
    themap.setMode(notetracker::NORMAL);
  }
  else
  {
    digitalWrite(GREENLEDPIN, LOW);
    themap.setMode(notetracker::ARP_UP);
  }
}

/* void dn_btn_func()
 *  
 *  Called when button reader detects arpeggio up button has been pressed.
 *  
 *  If not in dn mode, turn on up mode.
 *  If in dn mode, stops arpeggiator.
 */
void dn_btn_func()
{
#if VERBOSE  
  Serial.println("Dn!");
#endif
  
  if(themap.getMode() == notetracker::ARP_DN)
  {
    digitalWrite(GREENLEDPIN, HIGH);
    themap.setMode(notetracker::NORMAL);
  }
  else
  {
    digitalWrite(GREENLEDPIN, LOW);
    themap.setMode(notetracker::ARP_DN);
  }
}

/* void short_btn_func()
 *  
 *  Toggles staccato articulations
 *  Works independently of arpeggiator enablement.
 */
void short_btn_func()
{
#if VERBOSE  
  Serial.print("Short!");
#endif

  if(themap.getShort())
  {
    themap.setShort(false);
  }
  else
  {
    themap.setShort(true);
  }
}

/* Button behavior function array for ease of referencing using index
 *  
 */
void(*func_array[3])(void) = 
{
  up_btn_func,
  dn_btn_func,
  short_btn_func
};

/* void check_buttons()
 *  
 *  Implements debounced button polling for the 3 buttons on then MIDI shield.
 *  
 *  Buttons are active low, pulled up.
 *  On a poll cycle, reads each button.
 *  If button is pressed (LOW), it counts up.
 *  If button is held for enough cycles, it calls the indirect routine for the button.
 *  When button is released, debounce counter clears.
 */
void check_buttons()
{
  static uint8_t deb_array[3];
  uint8_t val;

  for(uint8_t i = 0; i < 3; i++)
  {
    // active low, pulled high
    val = digitalRead(i + UPBTNPIN);

    if(val == LOW)
    {
      if(deb_array[i] < BTN_DEBOUNCE+1)
      {
        deb_array[i]++;

        if(deb_array[i] == BTN_DEBOUNCE)
        {
          (*func_array[i])();
        }
      }
    }
    else
    {
      deb_array[i] = 0;
    }
  }
}

/////////////////////////////////////////////////////////////////////////
// Arduino boilerplate - setup() & loop()
/////////////////////////////////////////////////////////////////////////

void setup()
{
  // Output pins
  pinMode(GATEPIN, OUTPUT);   
  pinMode(REDLEDPIN, OUTPUT);
  pinMode(GREENLEDPIN, OUTPUT);

  digitalWrite(REDLEDPIN, HIGH);
  digitalWrite(GREENLEDPIN, HIGH);

  // Button pins
  pinMode(UPBTNPIN, INPUT_PULLUP);
  pinMode(DNBTNPIN, INPUT_PULLUP);
  pinMode(SHORTBTNPIN, INPUT_PULLUP);

  Serial.begin(115200); //This pipes to the serial monitor

  Wire.begin();

  // Initiate MIDI communications, listen to all channels
  // .begin sets the thru mode to on, so we'll have to turn it off if we don't want echo
  MIDI.begin(MIDI_CHANNEL_OMNI);

  MIDI.turnThruOff();

  // so it is called upon reception of a NoteOn.
  MIDI.setHandleNoteOn(handleNoteOn);  // Put only the name of the function
  // Do the same for NoteOffs
  MIDI.setHandleNoteOff(handleNoteOff);
  MIDI.setHandleControlChange(handleCC);
  MIDI.setHandlePitchBend(handlePitchBend);

  MsTimer2::set(tempo_delay, timer_callback);
  MsTimer2::start();

  Serial.println("setup complete");
}

void loop()
{
  // Pump the MIDI parser as quickly as we can.
  // This will invoke the callbacks when messages are parsed.
  MIDI.read();

  // check the tempo pot.
  check_pots();

  // check panel buttons
  check_buttons();
  
  if(send_tick)
  {
    send_tick = false;
    
    tick_func();

    MsTimer2::stop();
    MsTimer2::set(tempo_delay, timer_callback);
    MsTimer2::start();
  }

}

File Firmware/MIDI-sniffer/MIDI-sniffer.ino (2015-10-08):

/******************************************************************************
MIDI-sniffer.ino
Use SparkFun MIDI Shield as a MIDI data analyzer.

Byron Jacquot, SparkFun Electronics
October 8, 2015
https://github.com/sparkfun/MIDI_Shield/tree/V_1.5/Firmware/MIDI-sniffer

Reads all events arriving over MIDI, and turns them into descriptive text.
If you hold the button on D2, it will switch to display the raw hex values arriving,
which can be useful for viewing incomplete messages and running status.

Resources:

  Requires that the MIDI Sheild be configured to use soft serial on pins 8 & 9, 
  so that debug text can be printed to the hardware serial port.

  This code is dependent on the FortySevenEffects MIDI library for Arduino.
  https://github.com/FortySevenEffects/arduino_midi_library
  This was done using version 4.2, hash fb693e724508cb8a473fa0bf1915101134206c34
  This library is now under the MIT license, as well.
  You'll need to install that library into the Arduino IDE before compiling.

  
Development environment specifics:
  It was developed for the Arduino Uno compatible SparkFun RedBoard, with a  SparkFun
  MIDI Shield.
    
  Written, compiled and loaded with Arduino 1.6.5

This code is released under the [MIT License](http://opensource.org/licenses/MIT).

Please review the LICENSE.md file included with this example. If you have any questions 
or concerns with licensing, please contact techsupport@sparkfun.com.

Distributed as-is; no warranty is given.
******************************************************************************/


#include <SoftwareSerial.h>
#include <MsTimer2.h>
#include <MIDI.h>

#define PIN_RAW_INPUT 2

#define PIN_POT_A0 0
#define PIN_POT_A1 1

static const uint16_t DEBOUNCE_COUNT = 50;

// Need to use soft serial, so we can report what's happening
// via messages on hard serial.
SoftwareSerial SoftSerial(8, 9);

/* Args:
   - type of port to use (hard/soft)
   - port object name
   - name for this midi instance
*/
MIDI_CREATE_INSTANCE(SoftwareSerial, SoftSerial, MIDI);
// This doesn't make much sense to use with hardware serial, as it needs 
// hard serial to report what it's seeing...

void setup()
{
  // put your setup code here, to run
  once:

  // LED outputs
  Serial.begin(19200);
  Serial.println("Setting up");

  // do I need to init the soft serial port?
  // No - MIDI Lib will do it.

  // We want to receive messages on all channels
  MIDI.begin(MIDI_CHANNEL_OMNI);
  
  // We also want to echo the input to the output, 
  // so the sniffer can be dropped inline when things misbehave.
  MIDI.turnThruOn();

  pinMode(PIN_RAW_INPUT, INPUT_PULLUP);

}

void loop()
{
  static uint8_t  ticks = 0;
  static uint8_t  old_ticks = 0;


  // put your main code here, to run repeatedly:

  if(digitalRead(PIN_RAW_INPUT) == LOW)
  {
    // If you hold button D2 on the shield, we'll print
    // the raw hex values from the MIDI input.
    //
    // This can be useful if you need to troubleshoot issues with
    // running status

    byte input;
    if(SoftSerial.available() != 0)
    {
      input = SoftSerial.read();
    
      if(input & 0x80)
      {
        Serial.println();
      }
      Serial.print(input, HEX);
      Serial.print(' ');
    }
  }
  else
  {
    // turn the crank...
    if (  MIDI.read())
    {
      switch (MIDI.getType())
      {
        case midi::NoteOff :
          {
            Serial.print("NoteOff, chan: ");
            Serial.print(MIDI.getChannel());
            Serial.print(" Note#: ");
            Serial.print(MIDI.getData1());
            Serial.print(" Vel#: ");
            Serial.println(MIDI.getData2());
          }
          break;
        case midi::NoteOn :
          {
            uint8_t vel;

            Serial.print("NoteOn, chan: ");
            Serial.print(MIDI.getChannel());
            Serial.print(" Note#: ");
            Serial.print(MIDI.getData1());
            Serial.print(" Vel#: ");
            vel = MIDI.getData2();
            Serial.print(vel);
            if (vel == 0)
            {
              Serial.print(" *Implied off*");
            }
            Serial.println();
          }
          break;
        case midi::AfterTouchPoly :
          {
            Serial.print("PolyAT, chan: ");
            Serial.print(MIDI.getChannel());
            Serial.print(" Note#: ");
            Serial.print(MIDI.getData1());
            Serial.print(" AT: ");
            Serial.println(MIDI.getData2());
          }
          break;
        case midi::ControlChange :
          {
            Serial.print("Controller, chan: ");
            Serial.print(MIDI.getChannel());
            Serial.print(" Controller#: ");
            Serial.print(MIDI.getData1());
            Serial.print(" Value: ");
            Serial.println(MIDI.getData2());
          }
          break;
        case midi::ProgramChange :
          {
            Serial.print("PropChange, chan: ");
            Serial.print(MIDI.getChannel());
            Serial.print(" program: ");
            Serial.println(MIDI.getData1());
          }
          break;
        case midi::AfterTouchChannel :
          {
            Serial.print("ChanAT, chan: ");
            Serial.print(MIDI.getChannel());
            Serial.print(" program: ");
            Serial.println(MIDI.getData1());

          }
          break;
        case midi::PitchBend :
          {
            uint16_t val;

            Serial.print("Bend, chan: ");
            Serial.print(MIDI.getChannel());

            // concatenate MSB,LSB
            // LSB is Data1
            val = MIDI.getData2() << 7 | MIDI.getData1();

            Serial.print(" value: 0x");
            Serial.println(val, HEX);


          }
          break;
        case midi::SystemExclusive :
          {
            // Sysex is special.
            // could contain very long data...
            // the data bytes form the length of the message,
            // with data contained in array member
            uint16_t length;
            const uint8_t  * data_p;

            Serial.print("SysEx, chan: ");
            Serial.print(MIDI.getChannel());
            length = MIDI.getSysExArrayLength();
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

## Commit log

2014-04-29 Initial Commit with Brd/Sch Files
    [MIDI_Shield.brd, MIDI_Shield.sch]
2014-05-19 Added pin 2 ground, 0603, oshw, v#, trace/sch rework
    [MIDI_Shield.brd, MIDI_Shield.sch]
2015-01-19 Adding in Firmware and board files
    [SparkFun_MIDI_Shield.brd, SparkFun_MIDI_Shield.sch]
2015-01-19 Updating to current board files
    [SparkFun_MIDI_Shield-v13.brd, SparkFun_MIDI_Shield-v13.sch, SparkFun_MIDI_Shield.brd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]
2015-02-13 Updating to V1.5.
    0603 footprints.
    R3 shield footprint.
    Redrew MIDI connectors to match physical parts.
    Added optional jumpers for power-over-midi.
    General component updates, PROD_IDs and cleanup.
    [SparkFun_MIDI_Shield-v13.brd, SparkFun_MIDI_Shield-v13.sch, SparkFun_MIDI_Shield.brd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]
2015-02-16 Updates after engineering review.
    Added jumper to allow optional soft serial.
    [SparkFun_MIDI_Shield.brd, SparkFun_MIDI_Shield.sch]
2015-02-17 Updates after QC checklist.
    [SparkFun_MIDI_Shield.brd, SparkFun_MIDI_Shield.sch]
2015-02-17 Fixed 3 way junction net near LEDs
    Just cleaning up 3 way net junction on VCC side of LEDs
    [SparkFun_MIDI_Shield.sch]
2015-06-03 Prototype Revisions WIP
    [SparkFun_MIDI_Shield.brd, SparkFun_MIDI_Shield.sch]
2015-06-04 WIP Mostly complete.
    Proto issues handles.
    -Pots turn the right way.
    -Option for out vs thru.
    -JP/SJ terminology resolved.
    -More clearance around new connector component.
    [SparkFun_MIDI_Shield.brd, SparkFun_MIDI_Shield.sch]
2015-06-05 Board updates.
    Small tweaks before submission for review.
    [SparkFun_MIDI_Shield.brd, SparkFun_MIDI_Shield.sch]
2015-06-05 Small text change
    Fixing capitalization...really a change to get my renamed branch pushed
    (V_1.5 -> V_1.6).
    [SparkFun_MIDI_Shield.sch]
2015-06-08 Updates based on QC checklist.
    -Measures layer populated.
    -U1 got name/value.
    -Added stubs to some parts on schem.
    -Version # back to 1.5.
    [SparkFun_MIDI_Shield.brd, SparkFun_MIDI_Shield.sch]
2015-06-24 Fixing resistor obscured by output connector.
    [SparkFun_MIDI_Shield.brd]
2015-08-03 Fixing QC review issue with LP1,2 naming.
    TX & RX were transposed in jumper names.
    [SparkFun_MIDI_Shield.brd, SparkFun_MIDI_Shield.sch]
2015-08-04 created panel v15
    [SparkFun_MIDI_Shield_Panel_v15.brd]
2015-09-04 Adding a raw-hex mode.
    Sniffer ordinarily uses the output of the 47 Effects MIDI library, which
    handles all of the tricky stuff within MIDI.
    If you hold the D2 button, it switches to a raw hex display. This is
    useful for tracking down problems with running status, incomplete
    messages, etc.
    [midi-sniffer.ino]
2015-09-17 Incorporating test & demo sketches.
    [msec-to-bpm.ods]
2015-09-25 Some reformatting.
    Clock-gen was in a double nested directory
    (clock-gen/clock-gen/clock-gen.ino) - fixed.
    Added MIDI-2-CV & DAC integration test.
    [msec-to-bpm.ods]
2015-10-08 Re-orgasnizing code for release.
    Removed old sample.
    Added boilerplate & license references to all examples.
    Defaulted most examples to use hardware serial (except the sniffer,
    which need hardware serial to print).

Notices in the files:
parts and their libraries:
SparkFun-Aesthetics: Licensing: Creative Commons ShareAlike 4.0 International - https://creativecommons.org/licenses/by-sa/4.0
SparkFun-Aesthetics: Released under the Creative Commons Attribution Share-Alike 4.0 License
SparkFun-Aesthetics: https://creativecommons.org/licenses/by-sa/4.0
